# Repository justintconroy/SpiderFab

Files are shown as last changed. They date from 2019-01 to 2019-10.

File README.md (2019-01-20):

# Summary
SpiderFab is a quadruped spider robot based on the Spider robot by @regishsu , though not a direct fork. See:

* https://github.com/regishsu/SpiderRobot
* https://www.thingiverse.com/thing:1009659
* http://regishsu.blogspot.tw/2015/07/robot-quadruped-robot-re-design-3-round.html 
* Spider robot(quad robot, quadruped)-SG90 by regishsu is licensed under the GNU - GPL license.
* http://creativecommons.org/licenses/GPL/2.0/

The body, legs, original firmware code, and original electronics all come from regishsu. This
makes the body a bit wider to accomodate some wider batteries. To do this, the meshes were repaired,
and then imported into OpenSCAD for modification. This design also adds a place to mount a 5x7
perfboard on top, and a GDS (Glitter Dispersal System) weapon. Both attach to the top of the
widened spider robot's body. I also made the mounts for the servos 1mm taller since the
servos I got didn't fit in @regishsu 's design.

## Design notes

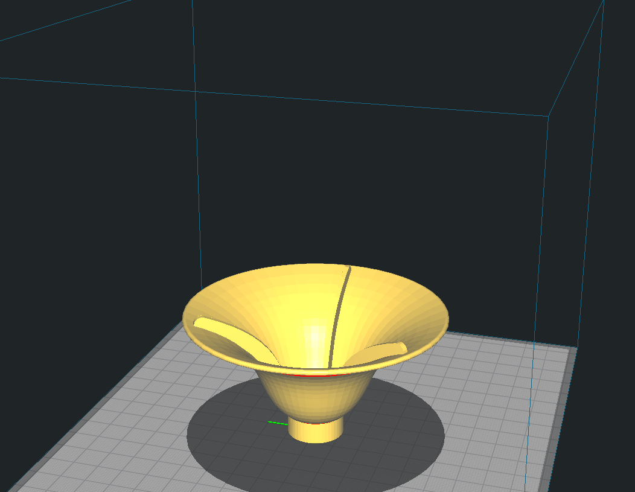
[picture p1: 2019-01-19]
cup_v1_screenshot.PNG

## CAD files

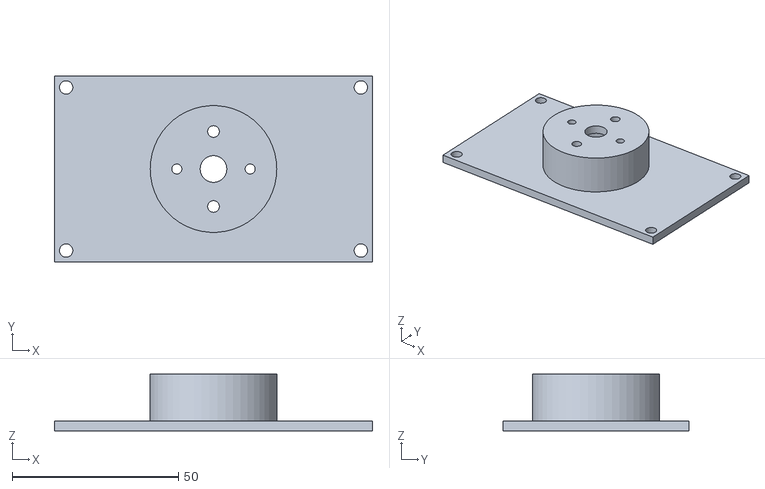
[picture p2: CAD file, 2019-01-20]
gds_top_case_v2.stl
95.5 x 56.0 x 17.0

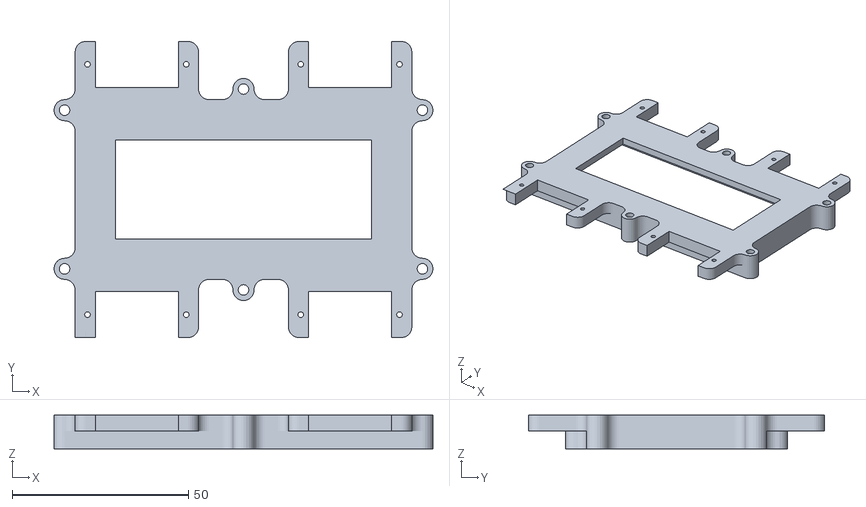
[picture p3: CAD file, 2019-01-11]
OriginalModel/body_u.stl
107.5 x 84.0 x 9.61

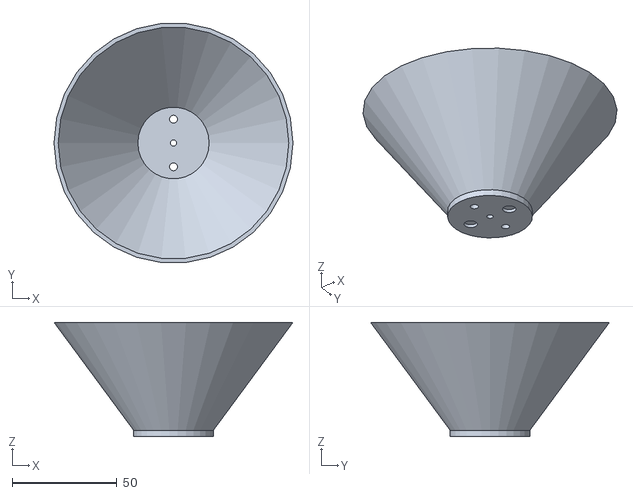
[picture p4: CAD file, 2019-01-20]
gds_holder_v1.stl
114.0 x 114.0 x 54.5

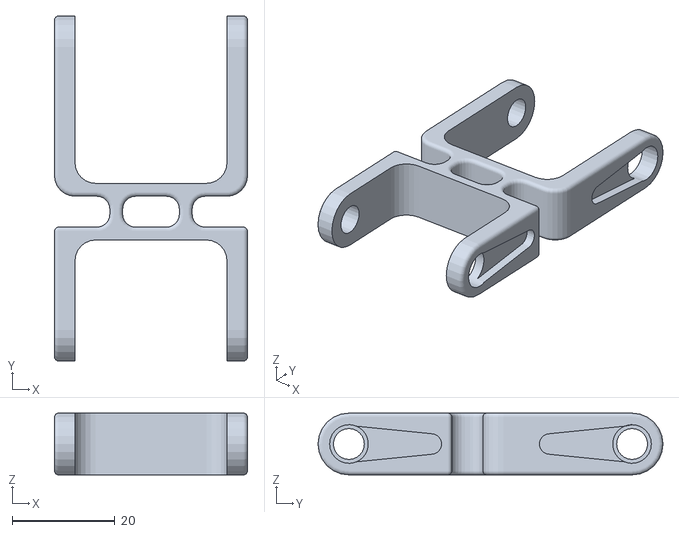
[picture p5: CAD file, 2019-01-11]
OriginalModel/femur_1.stl
37.5 x 67.0 x 12.0

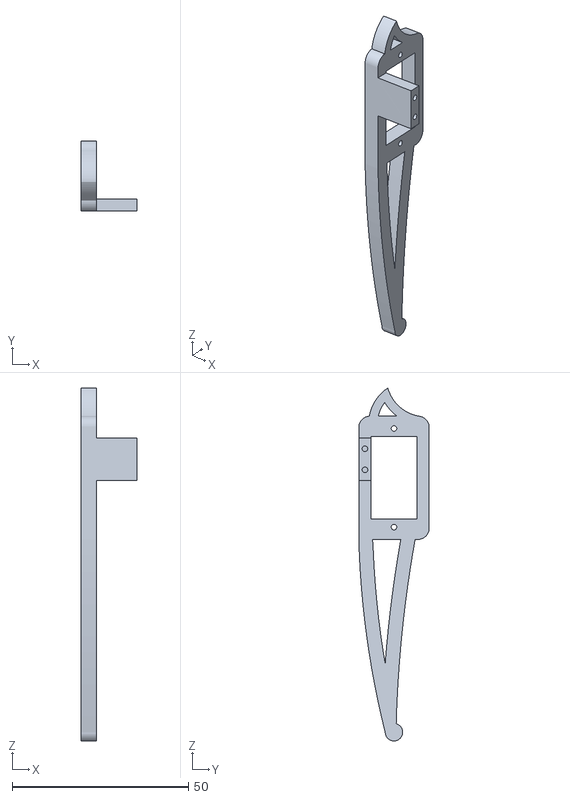
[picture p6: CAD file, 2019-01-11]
OriginalModel/tibia_r.stl
16.0 x 20.0 x 100.3

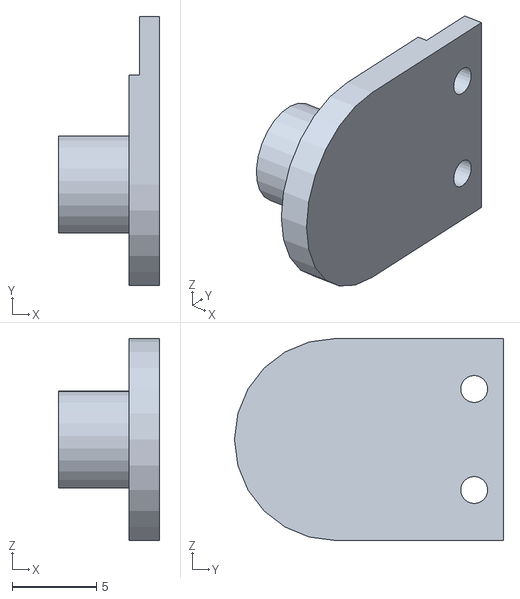
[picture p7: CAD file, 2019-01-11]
OriginalModel/s_hold.stl
6.00 x 16.0 x 12.0

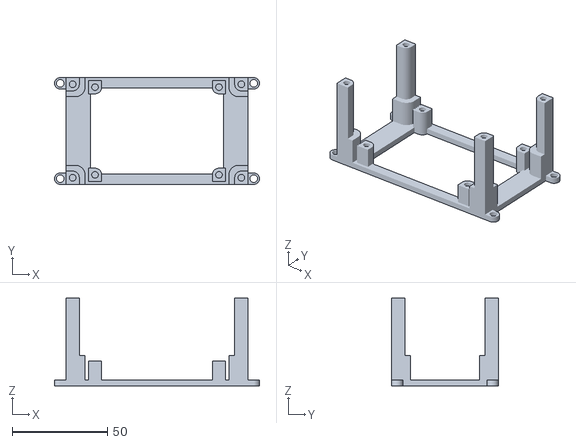
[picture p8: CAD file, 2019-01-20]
gds_bottom_case_v3.stl
107.5 x 56.0 x 46.0

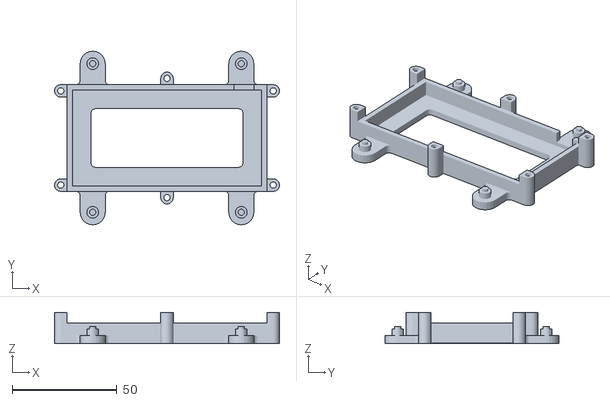
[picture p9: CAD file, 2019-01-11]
OriginalModel/body_d.stl
107.5 x 83.0 x 15.0

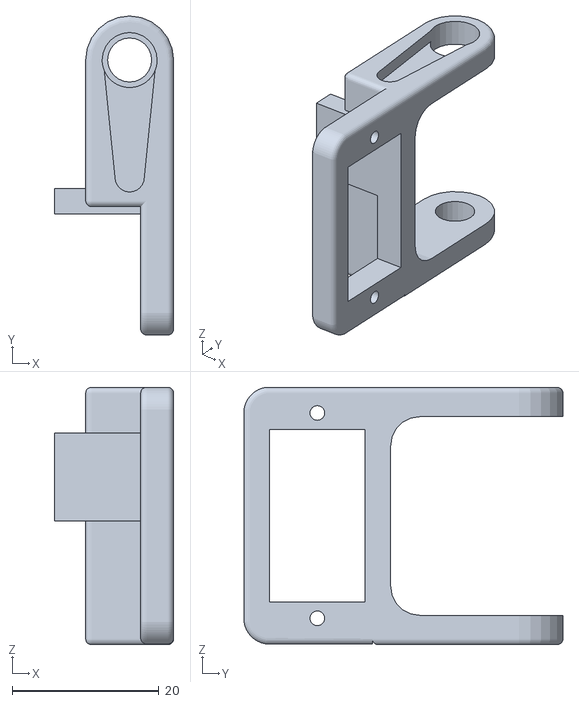
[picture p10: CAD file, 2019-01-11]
OriginalModel/coxa_l.stl
16.3 x 43.5 x 35.1

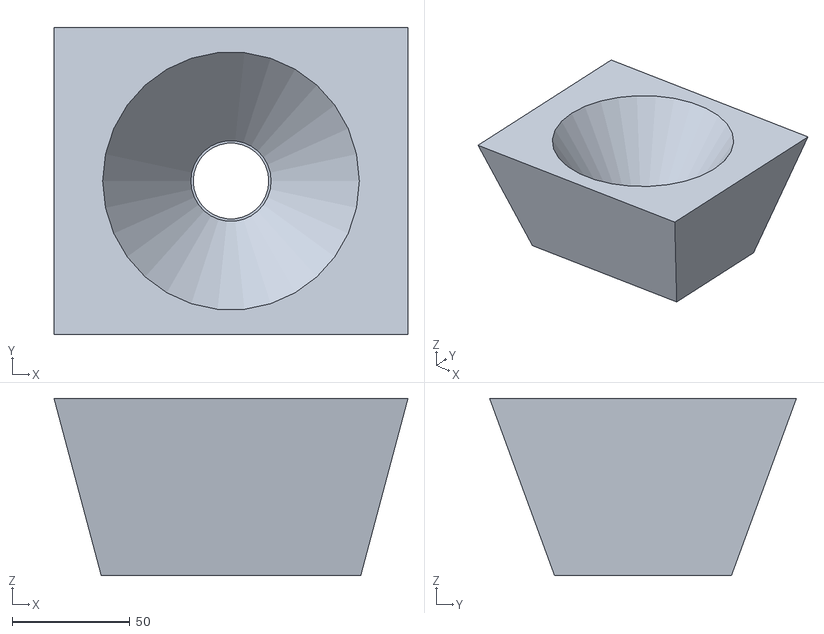
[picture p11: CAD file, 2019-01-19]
gds_case_prototype.stl
150.0 x 130.0 x 75.0

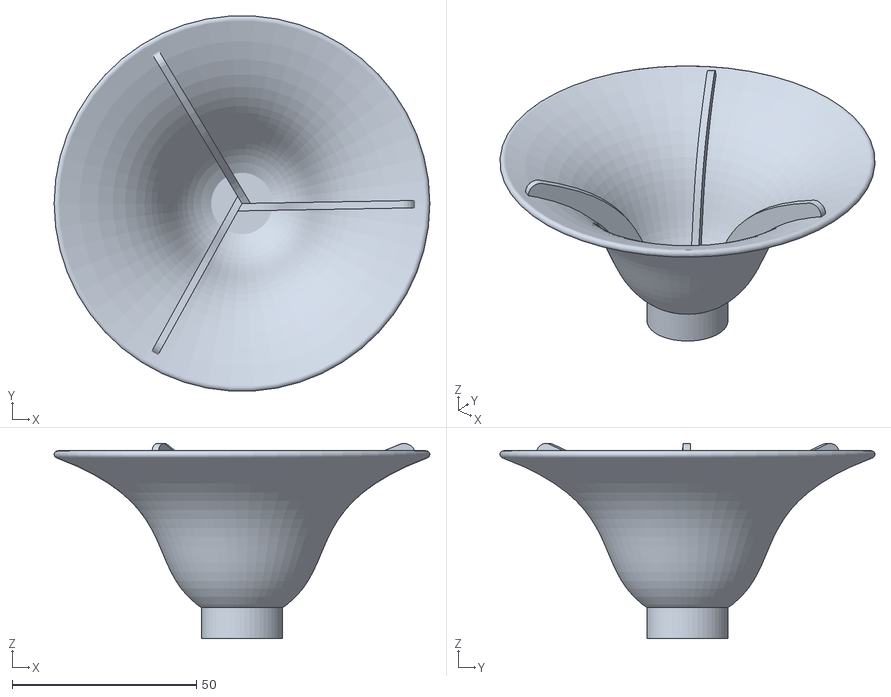
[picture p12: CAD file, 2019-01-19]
gds.stl
102.0 x 101.8 x 53.0

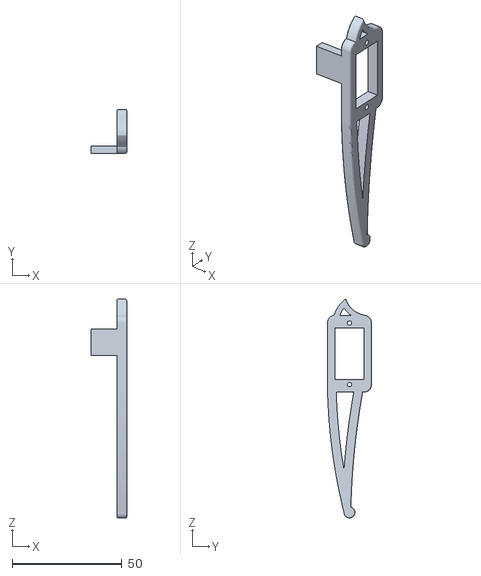
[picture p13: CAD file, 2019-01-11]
OriginalModel/tibia_l.stl
16.3 x 20.0 x 99.7

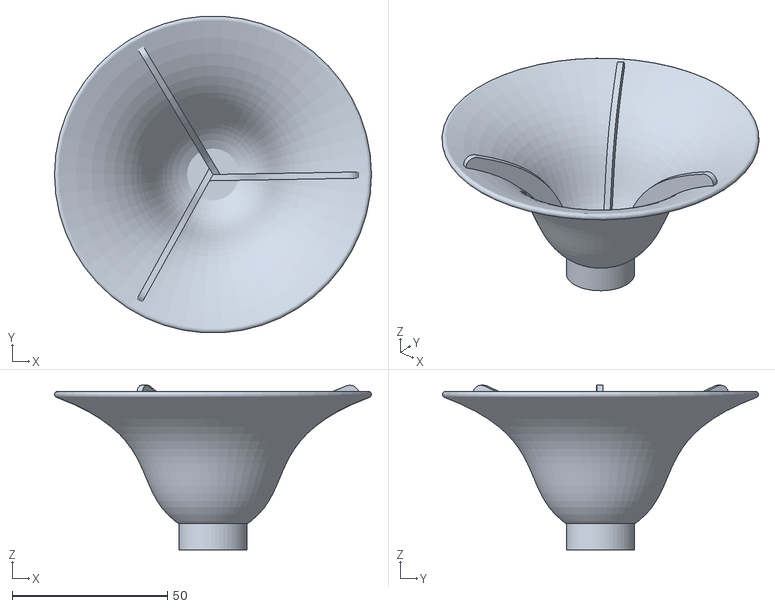
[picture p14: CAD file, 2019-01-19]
cup_v2.stl
102.0 x 101.8 x 53.0

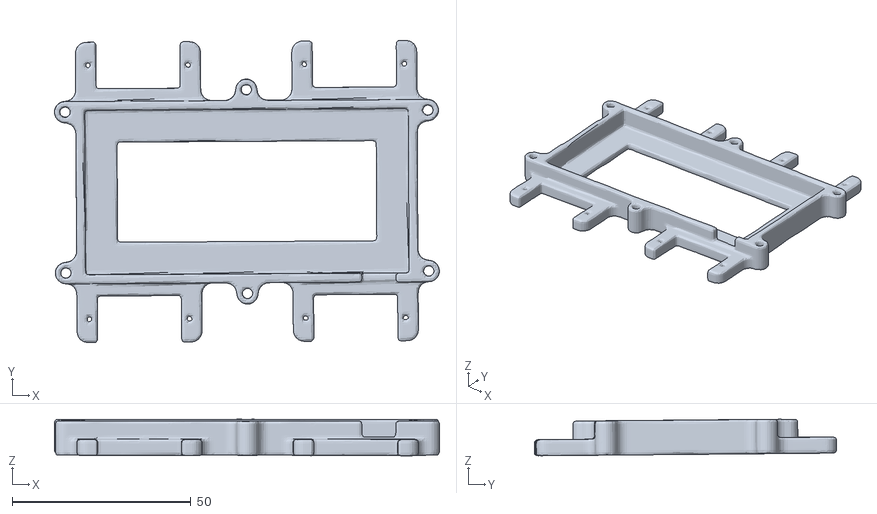
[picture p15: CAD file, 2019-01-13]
body_u_fixed.stl
107.7 x 84.5 x 10.2

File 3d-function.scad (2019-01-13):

use <scad-utils/lists.scad>

function f0(x,y) = sin(sqrt(pow(x,2) + pow(y,2)) * 180/PI) + 2;
function f1(x,y) = sqrt(pow(x,2) + pow(y,2) + 3);
function f(x,y) = 20*f0(x,y)/f1(x,y) + 4;

function p(x,y) = [x,y,f(x,y)];
function p0(x,y) = [x,y,0];

function rev(b,v) = b ? v : [v[3],v[2],v[1],v[0]];

function face(x,y,step=0.5) = [
	p(x,y+step),
	p(x+step,y+step),
	p(x+step,y),
	p(x+step,y),
	p(x,y),
	p(x,y+step)];

function fan(a,i,step=.5,size=20) =
	  a == 0 ? [[0,0,0],[i,-size,0],[i+step,-size,0]]
	: a == 1 ? [[0,0,0],[i+step,size,0],[i,size,0]]
	: a == 2 ? [[0,0,0],[-size,i+step,0],[-size,i,0]]
	:          [[0,0,0],[size,i,0],[size,i+step,0]];

function sidex(x,y,step=.5) = [p0(x,y),p(x,y,step),p(x+step,y,step),p0(x+step,y)];
function sidey(x,y,step=.5) = [p0(x,y),p(x,y,step),p(x,y+step,step),p0(x,y+step)];

function points(step=.5,size=20) = flatten(concat(
	// top surface
	[for(x=[-size:step:size-step],y=[-size:step:size-step]) face(x,y,step)],

	// bottom surface as a triangle fan
	[for(a=[0:3],i=[-size:step:size-step]) fan(a,i,step,size)],

	//sides
	[for(x=[-size:step:size-step],y=[-size,size])
		rev(y < 0, sidex(x,y,step))],
	[for(y=[-size:step:size-step],x=[-size,size])
		rev(x < 0, sidey(x,y,step))]
	));

module plot3d(step=.5,size=20)
{
	tcount = 2*pow(2*size/step,2) + 8*size/step;
	scount = 8*size/step;

	tfaces = [for(a=[0:3:3*(tcount-1)]) [a,a+1,a+2]];
	sfaces = [for(a=[3*tcount:4:3*tcount + 4*scount]) [a,a+1,a+2,a+3]];
	faces = concat(tfaces,sfaces);

	polyhedron(points(step,size),faces,convexity=8);
}

color("yellow") plot3d();

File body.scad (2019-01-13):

module body_u()
{
	//translate([-56,-128,-72])
		import("body_u_fixed.stl");
}
module body_d()
{
	//translate([-56,-128,0])
		import("body_d_fixed.stl");
}

module femur_1()
{
	import("femur_1.stl");
}

// Cut a thing in half. Use +1,-1,0 to determine which half.
module halve(axis=[0,0,0])
{
	intersection(){
		union(){
			children();
		}
		translate([1000*axis.x,1000*axis.y,1000*axis.z])
			cube([2000,2000,2000], center=true);

	}
}

module slice(size=[0,0,0],location=[0,0,0])
{
	intersection(){
		union(){
			children();
		}
		translate(location)
			cube(size,center=true);
	}
}

module stretch(width=5)
{
	union()
	{
		translate([0,width/2,0])
			halve([0,1,0])
				children();
		slice([100,width,100])
			children();
		translate([0,-width/2,0])
			halve([0,-1,0])
				children();
	}
}

module taller(height=1)
{
	union()
	{
		translate([0,0,height])
			slice([100,100,height + .5],[0,0,15.5])
				children();
		children();
	}
}

taller(1)
	import("tibia_r.stl");


//use<ruler.scad>;
//rotate([90,0,90])
	//translate([-11,0,25])
		//ruler(40);

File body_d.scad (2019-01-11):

use <body.scad>;
stretch(5)
	body_d();

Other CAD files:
OriginalModel/coxa_r.stl
tibia_r.stl
body_d_fixed.stl
tibia_l.stl
Cup_v1.stl
OriginalModel/spider-open-v1.skp
bowl.scad
gds.scad
gds_bottom_case.stl
gds_bottom_case_v2.stl
gds_case.scad
gds_top_case_v1.stl
parabaloid.scad
ruler.scad

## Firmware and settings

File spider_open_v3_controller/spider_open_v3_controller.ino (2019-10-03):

/* -----------------------------------------------------------------------------
  - Project: Remote control Crawling robot
  - Author:  panerqiang@sunfounder.com
  - Date:  2015/1/27
   -----------------------------------------------------------------------------
  - Overview
  - This project was written for the Crawling robot desigened by Sunfounder.
    This version of the robot has 4 legs, and each leg is driven by 3 servos.
  This robot is driven by a Ardunio Nano Board with an expansion Board.
  We recommend that you view the product documentation before using.
  - Request
  - This project requires some library files, which you can find in the head of
    this file. Make sure you have installed these files.
  - How to
  - Before use,you must to adjust the robot,in order to make it more accurate.
    - Adjustment operation
    1.uncomment ADJUST, make and run
    2.comment ADJUST, uncomment VERIFY
    3.measure real sites and set to real_site[4][3], make and run
    4.comment VERIFY, make and run
  The document describes in detail how to operate.
   ---------------------------------------------------------------------------*/

// modified by Regis for spider project, 2015-09-26
// add remote control by HC-06 bluetooth module


/* Includes ------------------------------------------------------------------*/
#include <Servo.h>    //to define and control servos
#include <FlexiTimer2.h>//to set a timer to manage all servos
// RegisHsu, remote control
#include <SerialCommand.h>
SerialCommand SCmd;   // The demo SerialCommand object

/* Servos --------------------------------------------------------------------*/
//define 12 servos for 4 legs
Servo servo[4][3];
//define servos' ports
const int servo_pin[4][3] = { {2, 3, 4}, {5, 6, 7}, {8, 9, 10}, {11, 12, 13} };

// GDS pins
const int gds_forward_pin = A4;
const int gds_reverse_pin = A5;
const int gds_pwn_pin = A6;
/* Size of the robot ---------------------------------------------------------*/
const float length_a = 55;
const float length_b = 77.5;
const float length_c = 27.5;
const float length_side = 71;
const float z_absolute = -28;
/* Constants for movement ----------------------------------------------------*/
const float z_default = -50, z_up = -30, z_boot = z_absolute;
const float x_default = 62, x_offset = 0;
const float y_start = 0, y_step = 40;
/* variables for movement ----------------------------------------------------*/
volatile float site_now[4][3];    //real-time coordinates of the end of each leg
volatile float site_expect[4][3]; //expected coordinates of the end of each leg
float temp_speed[4][3];   //each axis' speed, needs to be recalculated before each movement
float move_speed;     //movement speed
float speed_multiple = 1; //movement speed multiple
const float spot_turn_speed = 4;
const float leg_move_speed = 8;
const float body_move_speed = 3;
const float stand_seat_speed = 1;
volatile int rest_counter;      //+1/0.02s, for automatic rest
//functions' parameter
const float KEEP = 255;
//define PI for calculation
const float pi = 3.1415926;
/* Constants for turn --------------------------------------------------------*/
//temp length
const float temp_a = sqrt(pow(2 * x_default + length_side, 2) + pow(y_step, 2));
const float temp_b = 2 * (y_start + y_step) + length_side;
const float temp_c = sqrt(pow(2 * x_default + length_side, 2) + pow(2 * y_start + y_step + length_side, 2));
const float temp_alpha = acos((pow(temp_a, 2) + pow(temp_b, 2) - pow(temp_c, 2)) / 2 / temp_a / temp_b);
//site for turn
const float turn_x1 = (temp_a - length_side) / 2;
const float turn_y1 = y_start + y_step / 2;
const float turn_x0 = turn_x1 - temp_b * cos(temp_alpha);
const float turn_y0 = temp_b * sin(temp_alpha) - turn_y1 - length_side;
/* ---------------------------------------------------------------------------*/

/*
  - setup function
   ---------------------------------------------------------------------------*/
void setup()
{
  //start serial for debug
  Serial.begin(57600);
  Serial.println("Robot starts initialization");

  // RegisHsu, remote control
  // Setup callbacks for SerialCommand commands
  // action command 0-6,
  // w 0 1: stand
  // w 0 0: sit
  // w 1 x: forward x step
  // w 2 x: back x step
  // w 3 x: right turn x step
  // w 4 x: left turn x step
  // w 5 x: hand shake x times
  // w 6 x: hand wave x times
  SCmd.addCommand("w", action_cmd);

  SCmd.setDefaultHandler(unrecognized);

  //initialize default parameter
  set_site(0, x_default - x_offset, y_start + y_step, z_boot);
  set_site(1, x_default - x_offset, y_start + y_step, z_boot);
  set_site(2, x_default + x_offset, y_start, z_boot);
  set_site(3, x_default + x_offset, y_start, z_boot);
  for (int i = 0; i < 4; i++)
  {
    for (int j = 0; j < 3; j++)
    {
      site_now[i][j] = site_expect[i][j];
    }
  }
  //start servo service
  FlexiTimer2::set(20, servo_service);
  FlexiTimer2::start();
  Serial.println("Servo service started");
  //initialize servos
  servo_attach();
  Serial.println("Servos initialized");
  Serial.println("Robot initialization Complete");

  // Initialize GDS pins
  pinMode(gds_forward_pin, OUTPUT);
  pinMode(gds_reverse_pin, OUTPUT);
  pinMode(gds_pwn_pin, OUTPUT);
  Serial.println("GDS Online");

}


void servo_attach(void)
{
  for (int i = 0; i < 4; i++)
  {
    for (int j = 0; j < 3; j++)
    {
      servo[i][j].attach(servo_pin[i][j]);
      delay(100);
    }
  }
}

void servo_detach(void)
{
  for (int i = 0; i < 4; i++)
  {
    for (int j = 0; j < 3; j++)
    {
      servo[i][j].detach();
      delay(100);
    }
  }
}
/*
  - loop function
   ---------------------------------------------------------------------------*/
void loop()
{
  SCmd.readSerial();
}


void do_test(void)
{
  Serial.println("Stand");
  stand();
  delay(2000);
  Serial.println("Step forward");
  step_forward(5);
  delay(2000);
  Serial.println("Step back");
  step_back(5);
  delay(2000);
  Serial.println("Turn left");
  turn_left(5);
  delay(2000);
  Serial.println("Turn right");
  turn_right(5);
  delay(2000);
  Serial.println("Hand wave");
  hand_wave(3);
  delay(2000);
  Serial.println("Hand wave");
  hand_shake(3);
  delay(2000);
  Serial.println("Sit");
  sit();
  delay(5000);
}

// RegisHsu
// w 0 1: stand
// w 0 0: sit
// w 1 x: forward x step
// w 2 x: back x step
// w 3 x: right turn x step
// w 4 x: left turn x step
// w 5 x: hand shake x times
// w 6 x: hand wave x times
// w 7 x: Tilt body left by x amount
// w 8 x: Tilt body right by x amount
// w 9 x: Strafe left x steps
// w 10 x: Strafe right x steps
// w 21 1: Activate GDS
// w 21 0: Deactivate GDS
#define W_STAND_SIT    0
#define W_FORWARD      1
#define W_BACKWARD     2
#define W_LEFT         3
#define W_RIGHT        4
#define W_SHAKE        5
#define W_WAVE         6
#define W_LBODY        7
#define W_RBODY        8
#define W_LSTRAFE      9
#define W_RSTRAFE      10
#define W_GDS          21
void action_cmd(void)
{
  char *arg;
  int action_mode, n_step;
  Serial.print("Action: ");
  arg = SCmd.next();
  action_mode = atoi(arg);
  arg = SCmd.next();
  n_step = atoi(arg);

  switch (action_mode)
  {
    case W_FORWARD:
      Serial.println("Step forward");
      if (!is_stand())
        stand();
      step_forward(n_step);
      break;
    case W_BACKWARD:
      Serial.println("Step back");
      if (!is_stand())
        stand();
      step_back(n_step);
      break;
    case W_LEFT:
      Serial.println("Turn left");
      if (!is_stand())
        stand();
      turn_left(n_step);
      break;
    case W_RIGHT:
      Serial.println("Turn right");
      if (!is_stand())
        stand();
      turn_right(n_step);
      break;
    case W_STAND_SIT:
      if (n_step)
      {
        Serial.println("Stand");
        stand();
      }
      else
      {
        Serial.println("Sit");
        sit();
      }
      break;
    case W_SHAKE:
      Serial.println("Hand shake");
      hand_shake(n_step);
      break;
    case W_WAVE:
      Serial.println("Hand wave");
      hand_wave(n_step);
      break;
    case W_LBODY:
      Serial.println("Body left");
      if (!is_stand())
        stand();
      body_left(n_step);
      break;
    case W_RBODY:
      Serial.println("Body right");
      if (!is_stand())
        stand();
      body_right(n_step);
      break;
    case W_LSTRAFE:
      Serial.println("Strafe left");
      if (!is_stand())
        stand();
      strafe_left(n_step);
      break;
    case W_RSTRAFE:
      Serial.println("Strafe right");
      if (!is_stand())
        stand();
      //strafe_right(n_step);
      break;
    case W_GDS:
      Serial.print("GDS! ");
      if (is_stand())
        sit();
      gds(n_step);
      break;
    default:
      Serial.println("Error");
      break;
  }
}

// This gets set as the default handler, and gets called when no other command matches.
void unrecognized(const char *command) {
  Serial.println("What?");
}

/*
  - is_stand
   ---------------------------------------------------------------------------*/
bool is_stand(void)
{
  if (site_now[0][2] == z_default)
    return true;
  else
    return false;
}

/*
   - activate/deactivate GDS
*/
void gds(int n_step)
{
  switch(n_step)
  {
    case 0:
      // Stop
      Serial.println("STOP!");
      digitalWrite(gds_forward_pin, LOW);
      digitalWrite(gds_reverse_pin, LOW);
      analogWrite(gds_pwn_pin, 0);
      break;
    case 1:
      // Full speed ahead!
      Serial.println("FORWARD!");
      digitalWrite(gds_forward_pin, HIGH);
      digitalWrite(gds_reverse_pin, LOW);
      analogWrite(gds_pwn_pin, 255);
      break;
    case 2:
      // Full speed behind!
      Serial.println("REVERSE!");
      digitalWrite(gds_forward_pin, LOW);
      digitalWrite(gds_reverse_pin, HIGH);
      analogWrite(gds_pwn_pin, 255);
      break;
    default:
      break;
  }
}

/*
  - sit
  - blocking function
   ---------------------------------------------------------------------------*/
void sit(void)
{
  move_speed = stand_seat_speed;
  for (int leg = 0; leg < 4; leg++)
  {
    set_site(leg, KEEP, KEEP, z_boot);
  }
  wait_all_reach();
  Serial.println("OK");
}

/*
  - stand
  - blocking function
   ---------------------------------------------------------------------------*/
void stand(void)
{
  move_speed = stand_seat_speed;
  for (int leg = 0; leg < 4; leg++)
  {
    set_site(leg, KEEP, KEEP, z_default);
  }
  wait_all_reach();
  Serial.println("OK");
}


/*
  - spot turn to left
  - blocking function
  - parameter step steps wanted to turn
   ---------------------------------------------------------------------------*/
void turn_left(unsigned int step)
{
  move_speed = spot_turn_speed;
  while (step-- > 0)
  {
    if (site_now[3][1] == y_start)
    {
      //leg 3&1 move
      set_site(3, x_default + x_offset, y_start, z_up);
      wait_all_reach();

      set_site(0, turn_x1 - x_offset, turn_y1, z_default);
      set_site(1, turn_x0 - x_offset, turn_y0, z_default);
      set_site(2, turn_x1 + x_offset, turn_y1, z_default);
      set_site(3, turn_x0 + x_offset, turn_y0, z_up);
      wait_all_reach();

      set_site(3, turn_x0 + x_offset, turn_y0, z_default);
      wait_all_reach();

      set_site(0, turn_x1 + x_offset, turn_y1, z_default);
      set_site(1, turn_x0 + x_offset, turn_y0, z_default);
      set_site(2, turn_x1 - x_offset, turn_y1, z_default);
      set_site(3, turn_x0 - x_offset, turn_y0, z_default);
      wait_all_reach();

      set_site(1, turn_x0 + x_offset, turn_y0, z_up);
      wait_all_reach();

      set_site(0, x_default + x_offset, y_start, z_default);
      set_site(1, x_default + x_offset, y_start, z_up);
      set_site(2, x_default - x_offset, y_start + y_step, z_default);
      set_site(3, x_default - x_offset, y_start + y_step, z_default);
      wait_all_reach();

      set_site(1, x_default + x_offset, y_start, z_default);
      wait_all_reach();
    }
    else
    {
      //leg 0&2 move
      set_site(0, x_default + x_offset, y_start, z_up);
      wait_all_reach();

      set_site(0, turn_x0 + x_offset, turn_y0, z_up);
      set_site(1, turn_x1 + x_offset, turn_y1, z_default);
      set_site(2, turn_x0 - x_offset, turn_y0, z_default);
      set_site(3, turn_x1 - x_offset, turn_y1, z_default);
      wait_all_reach();

      set_site(0, turn_x0 + x_offset, turn_y0, z_default);
      wait_all_reach();

      set_site(0, turn_x0 - x_offset, turn_y0, z_default);
      set_site(1, turn_x1 - x_offset, turn_y1, z_default);
      set_site(2, turn_x0 + x_offset, turn_y0, z_default);
      set_site(3, turn_x1 + x_offset, turn_y1, z_default);
      wait_all_reach();

      set_site(2, turn_x0 + x_offset, turn_y0, z_up);
      wait_all_reach();

      set_site(0, x_default - x_offset, y_start + y_step, z_default);
      set_site(1, x_default - x_offset, y_start + y_step, z_default);
      set_site(2, x_default + x_offset, y_start, z_up);
      set_site(3, x_default + x_offset, y_start, z_default);
      wait_all_reach();

      set_site(2, x_default + x_offset, y_start, z_default);
      wait_all_reach();
    }
  }
  Serial.println("OK");
}

/*
  - spot turn to right
  - blocking function
  - parameter step steps wanted to turn
   ---------------------------------------------------------------------------*/
void turn_right(unsigned int step)
{
  move_speed = spot_turn_speed;
  while (step-- > 0)
  {
    if (site_now[2][1] == y_start)
    {
      //leg 2&0 move
      set_site(2, x_default + x_offset, y_start, z_up);
      wait_all_reach();

      set_site(0, turn_x0 - x_offset, turn_y0, z_default);
      set_site(1, turn_x1 - x_offset, turn_y1, z_default);
      set_site(2, turn_x0 + x_offset, turn_y0, z_up);
      set_site(3, turn_x1 + x_offset, turn_y1, z_default);
      wait_all_reach();

      set_site(2, turn_x0 + x_offset, turn_y0, z_default);
      wait_all_reach();

      set_site(0, turn_x0 + x_offset, turn_y0, z_default);
      set_site(1, turn_x1 + x_offset, turn_y1, z_default);
      set_site(2, turn_x0 - x_offset, turn_y0, z_default);
      set_site(3, turn_x1 - x_offset, turn_y1, z_default);
      wait_all_reach();

      set_site(0, turn_x0 + x_offset, turn_y0, z_up);
      wait_all_reach();

      set_site(0, x_default + x_offset, y_start, z_up);
      set_site(1, x_default + x_offset, y_start, z_default);
      set_site(2, x_default - x_offset, y_start + y_step, z_default);
      set_site(3, x_default - x_offset, y_start + y_step, z_default);
      wait_all_reach();

      set_site(0, x_default + x_offset, y_start, z_default);
      wait_all_reach();
    }
    else
    {
      //leg 1&3 move
      set_site(1, x_default + x_offset, y_start, z_up);
      wait_all_reach();

      set_site(0, turn_x1 + x_offset, turn_y1, z_default);
      set_site(1, turn_x0 + x_offset, turn_y0, z_up);
      set_site(2, turn_x1 - x_offset, turn_y1, z_default);
      set_site(3, turn_x0 - x_offset, turn_y0, z_default);
      wait_all_reach();

      set_site(1, turn_x0 + x_offset, turn_y0, z_default);
      wait_all_reach();

      set_site(0, turn_x1 - x_offset, turn_y1, z_default);
      set_site(1, turn_x0 - x_offset, turn_y0, z_default);
      set_site(2, turn_x1 + x_offset, turn_y1, z_default);
      set_site(3, turn_x0 + x_offset, turn_y0, z_default);
      wait_all_reach();

      set_site(3, turn_x0 + x_offset, turn_y0, z_up);
      wait_all_reach();

      set_site(0, x_default - x_offset, y_start + y_step, z_default);
      set_site(1, x_default - x_offset, y_start + y_step, z_default);
      set_site(2, x_default + x_offset, y_start, z_default);
      set_site(3, x_default + x_offset, y_start, z_up);
      wait_all_reach();

      set_site(3, x_default + x_offset, y_start, z_default);
      wait_all_reach();
    }
  }
  Serial.println("OK");
}

/*
  - go forward
  - blocking function
  - parameter step steps wanted to go
   ---------------------------------------------------------------------------*/
void step_forward(unsigned int step)
{
  move_speed = leg_move_speed;
  while (step-- > 0)
  {
    if (site_now[2][1] == y_start)
    {
      //leg 2&1 move
      set_site(2, x_default + x_offset, y_start, z_up);
      wait_all_reach();
      set_site(2, x_default + x_offset, y_start + 2 * y_step, z_up);
      wait_all_reach();
      set_site(2, x_default + x_offset, y_start + 2 * y_step, z_default);
      wait_all_reach();

      move_speed = body_move_speed;

      set_site(0, x_default + x_offset, y_start, z_default);
      set_site(1, x_default + x_offset, y_start + 2 * y_step, z_default);
      set_site(2, x_default - x_offset, y_start + y_step, z_default);
      set_site(3, x_default - x_offset, y_start + y_step, z_default);
      wait_all_reach();

      move_speed = leg_move_speed;

      set_site(1, x_default + x_offset, y_start + 2 * y_step, z_up);
      wait_all_reach();
      set_site(1, x_default + x_offset, y_start, z_up);
      wait_all_reach();
      set_site(1, x_default + x_offset, y_start, z_default);
      wait_all_reach();
    }
    else
    {
      //leg 0&3 move
      set_site(0, x_default + x_offset, y_start, z_up);
      wait_all_reach();
      set_site(0, x_default + x_offset, y_start + 2 * y_step, z_up);
      wait_all_reach();
      set_site(0, x_default + x_offset, y_start + 2 * y_step, z_default);
      wait_all_reach();

      move_speed = body_move_speed;

      set_site(0, x_default - x_offset, y_start + y_step, z_default);
      set_site(1, x_default - x_offset, y_start + y_step, z_default);
      set_site(2, x_default + x_offset, y_start, z_default);
      set_site(3, x_default + x_offset, y_start + 2 * y_step, z_default);
      wait_all_reach();

      move_speed = leg_move_speed;

      set_site(3, x_default + x_offset, y_start + 2 * y_step, z_up);
      wait_all_reach();
      set_site(3, x_default + x_offset, y_start, z_up);
      wait_all_reach();
      set_site(3, x_default + x_offset, y_start, z_default);
      wait_all_reach();
    }
  }
  Serial.println("OK");
}

/*
  - go back
  - blocking function
  - parameter step steps wanted to go
   ---------------------------------------------------------------------------*/
void step_back(unsigned int step)
{
  move_speed = leg_move_speed;
  while (step-- > 0)
  {
    if (site_now[3][1] == y_start)
    {
      //leg 3&0 move
      set_site(3, x_default + x_offset, y_start, z_up);
      wait_all_reach();
      set_site(3, x_default + x_offset, y_start + 2 * y_step, z_up);
      wait_all_reach();
      set_site(3, x_default + x_offset, y_start + 2 * y_step, z_default);
      wait_all_reach();

      move_speed = body_move_speed;

      set_site(0, x_default + x_offset, y_start + 2 * y_step, z_default);
      set_site(1, x_default + x_offset, y_start, z_default);
      set_site(2, x_default - x_offset, y_start + y_step, z_default);
      set_site(3, x_default - x_offset, y_start + y_step, z_default);
      wait_all_reach();

      move_speed = leg_move_speed;

      set_site(0, x_default + x_offset, y_start + 2 * y_step, z_up);
      wait_all_reach();
      set_site(0, x_default + x_offset, y_start, z_up);
      wait_all_reach();
      set_site(0, x_default + x_offset, y_start, z_default);
      wait_all_reach();
    }
    else
    {
      //leg 1&2 move
      set_site(1, x_default + x_offset, y_start, z_up);
      wait_all_reach();
      set_site(1, x_default + x_offset, y_start + 2 * y_step, z_up);
      wait_all_reach();
      set_site(1, x_default + x_offset, y_start + 2 * y_step, z_default);
      wait_all_reach();

      move_speed = body_move_speed;

      set_site(0, x_default - x_offset, y_start + y_step, z_default);
      set_site(1, x_default - x_offset, y_start + y_step, z_default);
      set_site(2, x_default + x_offset, y_start + 2 * y_step, z_default);
      set_site(3, x_default + x_offset, y_start, z_default);
      wait_all_reach();

      move_speed = leg_move_speed;

      set_site(2, x_default + x_offset, y_start + 2 * y_step, z_up);
      wait_all_reach();
      set_site(2, x_default + x_offset, y_start, z_up);
      wait_all_reach();
      set_site(2, x_default + x_offset, y_start, z_default);
      wait_all_reach();
    }
  }
  Serial.println("OK");
}
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

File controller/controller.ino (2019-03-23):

/* Wireless Joystick Tank Steering Robot Example
 * by: Alex Wende
 * SparkFun Electronics
 * date: 9/28/16
 * 
 * license: Creative Commons Attribution-ShareAlike 4.0 (CC BY-SA 4.0)
 * Do whatever you'd like with this code, use it for any purpose.
 * Please attribute and keep this license.
 * 
 * This is example code for the Wireless Joystick to control a robot
 * using XBee. Plug the first Xbee into the Wireless Joystick board,
 * and connect the second to the SparkFun Serial Motor Driver.
 * 
 * Moving the left and right joystick up and down will change the
 * speed and direction of motor 0 and motor 1. The left trigger will
 * reduce the maximum speed by 5%, while the right trigger button
 * will increase the maximum speed by 5%.
 * 
 * Connections to the motor driver is as follows:
 * XBee - Motor Driver
 *   5V - VCC
 *  GND - GND
 * DOUT - RX
 * 
 * Power the motor driver with no higher than 11V!
 */

#define L_TRIG 6        // Pin used for left trigger
#define R_TRIG 3        // Pin used for right trigger

#define L_STICK 5   // Pin used for left joystick button
#define L_HORZ A2   // Pin used for left joystick horizontal
#define L_VERT A3   // Pin used for left joystick vertical

#define R_STICK 5   // Pin used for right joystick button
#define R_HORZ A1   // Pin used for right joystick horizontal
#define R_VERT A0   // Pin used for right joystick vertical

int8_t speedLevel = 20; //Maximum speed (%) = speedLevel * 5 (units are percent)

void setup() {
  Serial1.begin(9600); // Start serial communication with XBee at 9600 baud
  delay(10);

  Serial1.print("W7001\r\n"); // Set the bit in enable register 0x70 to 0x01

  pinMode(L_TRIG,INPUT_PULLUP); // Enable pullup resistor for left trigger
  pinMode(R_TRIG,INPUT_PULLUP); // Enable pullup resistor for right trigger
  pinMode(L_STICK,INPUT_PULLUP); // Enable pullup resistor for left stick
  pinMode(R_STICK,INPUT_PULLUP); // Enable pullup resistor for right stick
}

void loop() {
  int16_t leftStickVert, rightStickVert;    // We'll store the the analog joystick values here
  int16_t leftStickHorz, rightStickHorz;
  char buf0[10],buf1[10]; // character buffers used to set motor speeds

  // Read joysticks
  // Convert analog value range to motor speeds (in %)
  leftStickVert = (5-(analogRead(L_VERT)/93))*speedLevel;
  leftStickHorz = (5-(analogRead(L_HORZ)/93))*speedLevel;
  rightStickVert = (5-(analogRead(R_VERT)/93))*speedLevel;
  rightStickHorz = (5-(analogRead(R_HORZ)/93))*speedLevel;

  // Build motor 0 buffer
  if(leftStickVert > 90)
  {
    sprintf(buf0,"w 2 1\r\n");
  }
  else if (leftStickVert < -90)
  {
    sprintf(buf0,"w 1 1\r\n");
  }
  else
  {
    sprintf(buf0,"");
    //sprintf(buf0,"LV: %d\n", leftStickVert);
  }

  // Build motor 1 buffer
  if(leftStickHorz > 90)
  {
    sprintf(buf1,"w 3 1\r\n");
  }
  else if (leftStickHorz < -90)
  {
    sprintf(buf1,"w 4 1\r\n");
  }
  else
  {
    //sprintf(buf1,"LH: %d\n", leftStickHorz);
    sprintf(buf1,"");
  }

  // Send motor speeds
  delay(5);
  Serial1.print(buf0);
  delay(5);
  Serial1.print(buf1);
}

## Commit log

2019-01-11 Initial code commit.
    [body.scad, body_d.scad, body_d.stl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]
2019-01-13 Fix and adjust all the things.
    Made some parts wider or taller since my servos are a millimeter too
    tall. I also fixed up the meshes. I had to, because OpenSCAD wasn't
    having none of that.
    [body.scad, body_d_fixed.stl, body_u_fixed.stl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]
2019-01-13 Working on getting a GDS going.
    I have the basic shape I want, but apparently I did something wrong.
    When I try to do anything to it, I get CGAL errors. :-/
    [3d-function.scad, gds.scad, parabaloid.scad]
2019-01-13 We're gonna try something different with gds.
    Keeping this around in case I want to come back to this method.
    [bowl.scad]
2019-01-19 First iteration of the GDS.
    Printed better than expected. Drilled a hole in the bottom to test it
    with the motors. Works pretty good.
    [Cup_v1.stl, cup_v2.stl, gds_v1.scad]
2019-01-19 Added hole to the bottom of GDS.
    [gds.scad]
2019-01-19 Add stl to repo
    [gds.stl, gds_v1.scad]
2019-01-19 A prototype GDS case to test fit.
    [gds_case.scad, gds_case_prototype.stl]
2019-01-19 Modularized things and added electronics model.
    To better make the supports.
    [gds_case.scad]
2019-01-19 Add a "bottom case".
    It should connect to the existing body. It has a place to mount the
    perfboard, and some supports to attach the top matter to.
    [gds_bottom_case.stl, gds_case.scad]
2019-01-20 Fixed bottom case prototype.
    Apparently I didn't check the spacing on the perfboard at all on V2. :-/
    Also, thickened up the support columns to be sturdier.
    [gds_bottom_case_v2.stl, gds_bottom_case_v3.stl, gds_case.scad]
2019-01-20 Prototype of top case for fitting.
    [gds_case.scad, gds_top_case_v1.stl]
2019-01-20 Start some work on the GDS holder/shell.
    [gds_case.scad]
2019-01-20 The rest of the case, plus added test code from Regis Hsu.
    [gds_case.scad, gds_holder_v1.stl, gds_top_case_v2.stl]
2019-03-23 Things for the wireless (currently bricked) controller.
2019-03-23 A new controller for the spider robot.
    It's got buttons and such.
